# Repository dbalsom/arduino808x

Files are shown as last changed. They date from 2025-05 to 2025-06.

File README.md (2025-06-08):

# ArduinoX86
arduino8088_pcb

### About ArduinoX86
I've written a blog article that gives an overview of this project and how it is used.

https://martypc.blogspot.com/2023/06/hardware-validating-emulator.html

This project was originally called Arduino8088, but then I expanded it to support the 8086, and then the 80186, and have plans to support 80286, so it is now named the suitably generic ArduinoX86.

### Description

This project expands on the basic idea of controlling a CPU via a microcontroller's GPIO pins to clock the CPU and read and write control and data signals.
This can be used to validate an emulator's accuracy, but also as a general method of exploring the operation of a CPU's instructions and timings.
This project specifically targets early Intel and compatible CPUs, such as the 8088, 8086, NEC V20, V30, and specific variants of the the Intel 80186. Future support for the 80286 is planned.

Where it differs from existing Raspberry Pi-based projects is that it uses an Arduino DUE for the expanded number of GPIO pins available. The DUE has enough GPIO to operate 808X-compatible CPUs in Maximum mode. This enables several useful signals to be read such as the QS0 & QS1 processor instruction queue status lines, which give us more insight into the internal state of the CPU. We can also enable inputs such as READY, NMI, INTR, and TEST, so we can execute interrupts, NMIs, emulate wait states, and potentially even simulate FPU and DMA operations.

I have been using this project to validate the cycle-accuracy of my PC emulator, [MartyPC](https://github.com/dbalsom/martypc), and produce CPU test suites for emulators, covering the [8088](https://github.com/singleStepTests/8088/), [V20](https://github.com/SingleStepTests/v20) and [8086](https://github.com/singleStepTests/8086/) to date. 

This project has three main components:
  - The CPU server software, which runs on the Arduino, resets and initializes the CPU, loads the initial register state, then hands off control to the client, reading the final register state when complete.
  - The CPU client software, which runs on your computer and controls the CPU after the CPU server has set up initial register state as desired.
  - The CPU socket PCB HAT(s), which seat on top of the Arduino, and provide a physical interface between the CPU and GPIO lines.

The original Arduino8088 board utilized an Arduino MEGA, but this board is now considered deprecated for this project. As of the current release, an [Arduino DUE](https://store.arduino.cc/products/arduino-due) should be used instead. Although the DUE has 3v GPIO, the current board design is modified for 3V operation. Several models of the 80C88 tolerate 3V well despite being 5V parts, due to the low clock rate employed.

Support for the newer [Arduino GIGA](https://store.arduino.cc/products/giga-r1-wifi) is in development but not quite complete. Unfortunately it seems to have insufficient power supply on the 3V line compared to the DUE.

A PCB hat for the 80286 that supports level shifting between 5V and 3V is in the design phase.

### 8086 Support

Revision 1.1 of the Arduino8088 board supports the 8086 and NEC V30 by adding a connection for the 8086's BHE pin. 

### 80186 Support

The ArduinoX86 cpu_server sketch supports operation of a low-voltage 80186. See the BOM section below for compatible parts. 
There is no PCB for the 80186, you will need to use a breakout board and connect directly to the Arduino DUE's headers. See [Using an 80186](https://github.com/dbalsom/arduinoX86/wiki/Using-an-80186) for more information.

## Can the CPU be clocked fast enough with an Arduino?

In short, no. We are well past the published minimum cycle times when executing programs via a serial protocol, cycle by cycle. NMOS process chips will fail to function in strange ways when clocked below this threshold. The issue is "dynamic logic" - logic gates that lose their state if not refrehsed electrically within a frequent enough interval. To function with ArduinoX86 a CMOS process CPU with a fully static core should be employed. These chips can be clocked down to 0Hz and still function. A list of compatible CPUs is provided in the BOM below.

## Credits

Inspired by and borrows from the Pi8088 validator created by Andreas Jonsson as part of the VirtualXT project:

https://github.com/andreas-jonsson/virtualxt/tree/develop/tools/validator/pi8088

A very similar project is homebrew8088's Raspberry Pi Hat:

https://github.com/homebrew8088/pi86

## To use

If you are using an 8088, 8086, V20 or V30, and you don't want to order and build the PCB, connect the GPIO pins to the CPU on a breadboard as specified in the KiCad project schematic.

If you are using an 80186, see the [wiki](https://github.com/dbalsom/arduinoX86/wiki/Using-an-80186) for connection instructions.

The main ArduinoX86 sketch, cpu_server, operates a simple binary serial protocol to execute operations on the CPU and read and write data, status and control signals. This is designed for integration with an emulator or instruction test generator.

Additionally, there is a sketch, 'run_program', that will take any user-supplied register state and array of instruction bytes defined in the source code, execute it, and print cycle traces and final register state. This is useful for investigating the timing and operation of certain instructions without needing any external software integrations, however it is restricted in the number of memory reads or writes it can support, due to the limited RAM on the Arduino MEGA (8k!) 'run_program' does not currently support the DUE.

An example application for cpu_server is provided, written in Rust, in the /crates/exec_program directory. It demonstrates how to upload arbitrary code to the ArduinoX86 and display cycle traces. The client will emulate the entire address space and set up a basic IVT.

## PCB
pcb_shield50

KiCad project files for the PCB are supplied. 

Version 1.1 adds a connection for the 8086's BHE pin, which is used by the 8086/V30/80186/80286 to drive the upper half of the 16-bit data bus.

> [!WARNING]  
> Please read all the notes in the next section before ordering/assembling parts. Failure to heed warnings will cause damage to your Arduino.

> [!CAUTION]
> Depending on the CPU used and the presence of an 8288 support chip, you may exceed the rated 3V power supply of the Arduino DUE.
> If your Arduino immediately turns off or does not turn on at all, you are likely triggering the overcurrent protection.
> 
> You can cut off the 3V supply lead from the header socket and provide external power from the top of the HAT.
>
> DO NOT connect external power to the 3V header without cutting the pin to the Arduino! Feeding current back into 3V OUT can damage your Arduino.

# BOM
- A compatible CPU:
  - For 8088, I recommend a CMOS variant such as a Harris or Oki 80C88. CMOS versions of the 8088 and 8086 were made by a number of manufacturers; all of them should work.
  - For 8086, Intel directly produced an 80C86 which works, so you might as well use it. The Harris 80C86 has also been tested but has minor differences. 
  - The NEC V20 and V30 were CMOS process CPUs and work as well.
  - Some NMOS process CPUs may work - the AMD D8088 will work, but the AMD D8086-2 will not. The original Intel 8088 (C)1978 will not function properly.
  - For 80186, I recommend the Intel 80L186EB. See [Using an 80186](https://github.com/dbalsom/arduinoX86/wiki/Using-an-80186) for more information.

  - For 80286, a level-shifting HAT is required as no 3V 286 was produced. A CMOS variant such as the Harris 80C286 is required. The CPU should be a PLCC68 form factor.
    The 286 HAT is still in the design phase.

> [!TIP]
> Beware of counterfeits on eBay and other online vendors. A legitimate chip will not look shiny and new with perfect printing on it. At best, you may get a functional
> CPU that has been resurfaced and reprinted, but there's not telling what you're actualy testing. 

- Optional: If using an 8088 or 8086, you can socket an Intel 8288 or OKI 82C88 Bus Controller.
  A CMOS version it not necessarily required, but they use less power.
  
  The 8288 is easily emulated but its ALE output is used to drive the LED on the Arduino8088 HAT.
  Change the `EMULATE_8288` define to 0 if using a physical 8288.

- A set of Arduino stacking headers (also usable with DUE) 
https://www.amazon.com/Treedix-Stacking-Headers-Stackable-Compatible/dp/B08G4FGBPQ

- A DIP-40 and (optionally) DIP-20 socket
  - Optional but highly recommended: A ZIF socket such as [https://www.amazon.com/-/en/gp/product/B00B886OZI](https://www.amazon.com/-/en/gp/product/B00B886OZI)
    to avoid breaking pins on repeated insertions

- (2x) 0805 0.047uf bypass capacitors
  https://www.mouser.com/ProductDetail/80-C0805C473KARAUTO

- Optional: A 12mm, active buzzer with 7.6mm pin spacing. 

  - For DUE: A 3V piezoelectric, low power buzzer <= 6mA
    https://www.mouser.com/ProductDetail/Mallory-Sonalert/PK-11N40PQ?qs=SXHtpsd1MbZ%252B7jeUyAAOVA%3D%3D
    
  - For MEGA: Any 3-5V buzzer <= 30mA
 
> [!WARNING]  
> Only connect an electromagnetic buzzer if using an Arduino MEGA.  The DUE has much lower GPIO max current supply.

- (2x) 750Ohm resistors (for LEDs)
  https://www.mouser.com/ProductDetail/667-ERA-6AED751V

- (2x) Any 0805 ~2V LED of your choice with 1.8-1.9mA forward current
  - https://www.mouser.com/ProductDetail/604-APTD2012LCGCK (Green)
  - https://www.mouser.com/ProductDetail/604-APT2012LSECKJ4RV (Orange)
 
- RS232 board for debug output - choose gender based on your desired cabling
  - https://www.amazon.com/Ultra-Compact-RS232-Converter-1Mbps/dp/B074BMLM11 (male)
  - https://www.amazon.com/Ultra-Compact-RS232-Converter-Female/dp/B074BTGLJN (female)
    
> [!WARNING]  
> DO NOT connect 5V to the RS232 board on the Arduino DUE. You will feed 5V into the RX GPIO pin and cause irreperable damage.

# Project Structure

## /asm

Assembly language files, intended to be assembled with NASM. To execute code on the ArduinoX86, one must supply two
binary files, one containing the program to be executed, and one containing the register values to load onto the CPU
before program execution. 

## /crates/ard808x_client

A library crate that implements a client for the ArduinoX86's serial protocol.

## /crates/ard808x_cpu

A library crate built on top of the `ard808x_client` crate, this provides a `RemoteCpu` struct that models CPU state 
and can execute programs.

## /crates/exec_program

A binary implementing an interface for the `ard808x_cpu` crate that will load a provided register state binary and 
execute the specified program binary.

## /pcb

Contains the KiCad project files and Gerber files for the Arduino8088 PCB.

## /sketches/cpu_server

The main Arduino sketch for ArduinoX86. Implements a server for a serial protocol enabling remote control of a 16-bit
Intel CPU on the Arduino DUE.

## /sketches/run_program

An older sketch that can execute a program directly on the Arduino MEGA. Supports the 8088 only.

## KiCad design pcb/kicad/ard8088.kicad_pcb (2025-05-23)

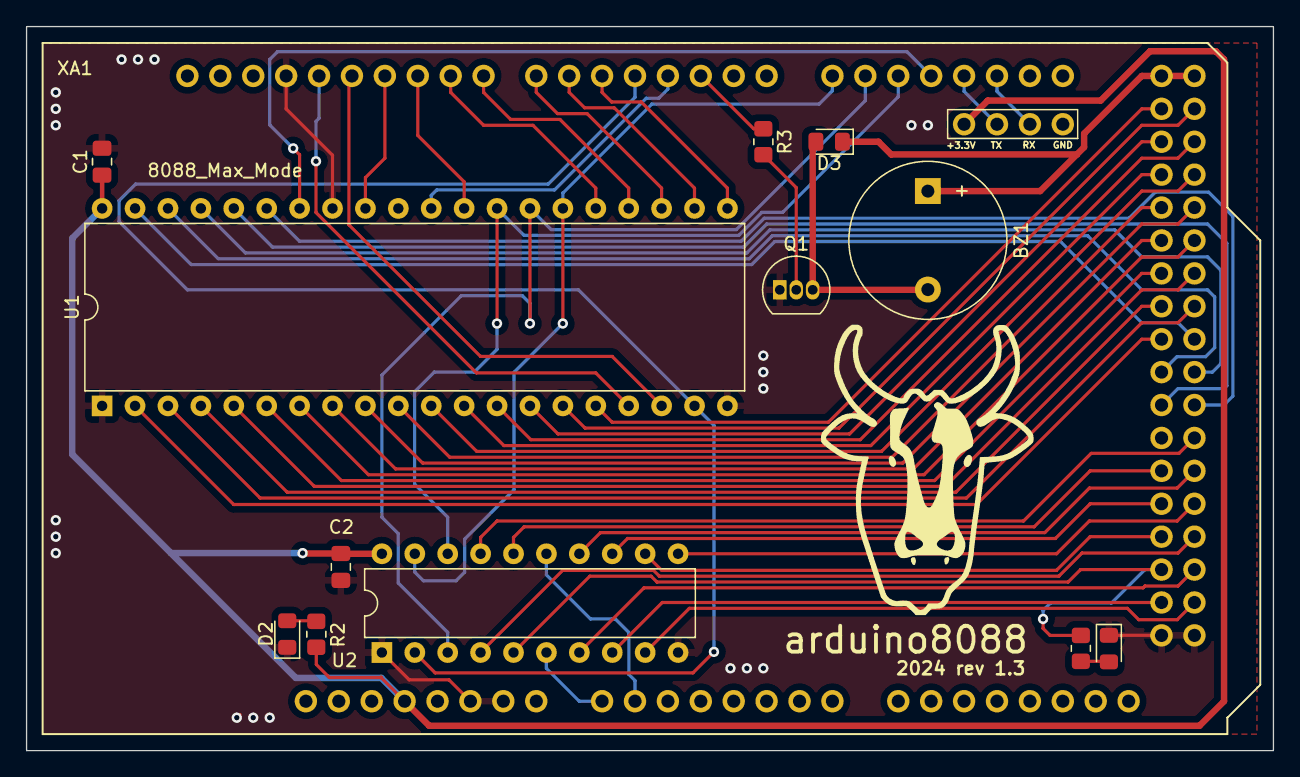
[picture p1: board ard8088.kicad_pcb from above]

Board: 2 copper layers, 96.2 x 55.9 mm, 13 parts (0 on the bottom side), 58 nets.

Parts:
BZ1: Buzzer; Buzzer_12x9.5RM7.6
C1, C2: 0.1uf; C_0805_2012Metric_Pad1.18x1.45mm_HandSolder
D1, D2: LED; LED_0805_2012Metric_Pad1.15x1.40mm_HandSolder
D3: 1N4148; D_0805_2012Metric_Pad1.15x1.40mm_HandSolder
Q1: PN2222A; TO-92_Inline
R1: R1; R_0805_2012Metric_Pad1.20x1.40mm_HandSolder
R2, R3: R; R_0805_2012Metric_Pad1.20x1.40mm_HandSolder
U1: 8088_Max_Mode; DIP-40_W15.24mm
U2: 8288; DIP-20_W7.62mm
XA1: Arduino_Mega2560_Shield

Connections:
+3.3V: C1.1, C2.1, R2.1, U1.40 (VCC), U2.20 (VCC), XA1.3V3 (3.3V), XA1.S0
+5V: BZ1.1 (-), D3.1 (K), XA1.5V3 (5V), XA1.5V4 (5V)
/A8: U1.8 (A8), XA1.D30
/A9: U1.7 (A9), XA1.D31
/A10: U1.6 (A10), XA1.D32
/A11: U1.5 (A11), XA1.D33
/A12: U1.4 (A12), XA1.D34
/A13: U1.3 (A13), XA1.D35
/A14: U1.2 (A14), XA1.D36
/A15: U1.39 (A15), XA1.D37
/A16: U1.38 (A16/S3), XA1.D38
/A17: U1.37 (A17/S4), XA1.D39
/A18: U1.36 (A18/S5), XA1.D40
/A19: U1.35 (A19/S6), XA1.D41
/AD0: U1.16 (AD0), XA1.D22
/AD1: U1.15 (AD1), XA1.D23
/AD2: U1.14 (AD2), XA1.D24
/AD3: U1.13 (AD3), XA1.D25
/AD4: U1.12 (AD4), XA1.D26
/AD5: U1.11 (AD5), XA1.D27
/AD6: U1.10 (AD6), XA1.D28
/AD7: U1.9 (AD7), XA1.D29
/ALE: R1.1, U2.5 (ALE), XA1.D50
/CEN: U2.15 (CEN), XA1.A1
/CLK: U1.19 (CLK), U2.2 (CLK), XA1.D4
/DEN: U2.16 (DEN), XA1.D44
/DT/~R: U2.4 (DT/~R), XA1.D49
/INTR: U1.18 (INTR), XA1.D12
/MCE/~PDEN: U2.17 (MCE/~PDEN), XA1.D43
/NMI: U1.17 (NMI), XA1.D13
/QS1: U1.24 (QS1), XA1.D8
/QSO: U1.25 (QS0), XA1.D9
/READY: U1.22 (READY), XA1.D6
/RESET: U1.21 (RESET), XA1.D5
/S0: U1.26 (~S0), U2.19 (~S0), XA1.D14 (D14_TX3)
/S1: U1.27 (~S1), U2.3 (~S1), XA1.D15 (D15_RX3)
/S2: U1.28 (~S2), U2.18 (~S2), XA1.D16 (D16_TX2)
/ser0: XA1.D18 (D18_TX1), XA1.S1
/ser1: XA1.D19 (D19_RX1), XA1.S2
/~AEN: U2.6 (~AEN), XA1.A0
/~AIOWC: U2.12 (~AIOWC), XA1.D48
/~AMWC: U2.8 (~AMWC), XA1.D52
/~BHE: U1.34 (HIGH), XA1.D17 (D17_RX2)
/~INTA: U2.14 (~INTA), XA1.D45
/~IORC: U2.13 (~IORC), XA1.D46
/~IOWC: U2.11 (~IOWC), XA1.D47
/~LOCK: U1.29 (~LOCK), XA1.D10
/~MRDC: U2.7 (~MRDC), XA1.D51
/~MWTC: U2.9 (~MWTC), XA1.D53 (D53_SS)
/~RD: U1.32 (~RD), XA1.D11
/~RQ/~GT1: U1.30 (~RQ/~GT1), XA1.D3 (D3_INT1)
/~TEST: U1.23 (~TEST), XA1.D7
GND: C1.2, C2.2, D1.1 (K), D2.1 (K), Q1.1 (E), U1.1 (GND), U1.20 (GND), U1.33 (MN/~MX), U2.1 (IOB), U2.10 (GND), XA1.GND1 (GND), XA1.GND2 (GND), XA1.GND3 (GND), XA1.GND5 (GND), XA1.GND6 (GND), XA1.S3
unnamed: BZ1.2 (+), D3.2 (A), Q1.3 (C)
unnamed: D1.2 (A), R1.2
unnamed: D2.2 (A), R2.2
unnamed: Q1.2 (B), R3.2
unnamed: R3.1, XA1.D2 (D2_INT0)

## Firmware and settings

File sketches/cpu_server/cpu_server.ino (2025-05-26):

/*
    Arduino8088 Copyright 2022-2025 Daniel Balsom
    https://github.com/dbalsom/arduino_8088

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
    THE SOFTWARE IS PROVIDED “AS IS”, WITHOUT WARRANTY OF ANY KIND, EXPRESS OR
    IMPLIED, INCLUDING BUT NOT LIMITED TO THE WARRANTIES OF MERCHANTABILITY,
    FITNESS FOR A PARTICULAR PURPOSE AND NONINFRINGEMENT. IN NO EVENT SHALL THE
    AUTHORS OR COPYRIGHT HOLDERS BE LIABLE FOR ANY CLAIM, DAMAGES OR OTHER   
    LIABILITY, WHETHER IN AN ACTION OF CONTRACT, TORT OR OTHERWISE, ARISING
    FROM, OUT OF OR IN CONNECTION WITH THE SOFTWARE OR THE USE OR OTHER
    DEALINGS IN THE SOFTWARE.
*/
#include <Arduino.h>
#include "arduino8088.h"
#include "cpu_server.h"
#include "opcodes.h"

static Server SERVER;
static Cpu CPU;
static Intel8288 I8288;

registers LOAD_REGISTERS = {
  0x0000, // AX
  0x0000, // BX
  0x0000, // CX
  0x0000, // DX
  0x0000, // SS
  0x0000, // SP
  0x0000, // FLAGS
  0x0000, // IP
  0xFFFF, // CS
  0x0000, // DS
  0x0000, // ES
  0x0000, // BP
  0x0000, // SI
  0x0000, // DI
};

// Register load routine. This program gets patched with the client supplied register values.
// It uses MOVs and POPs to set the register state as specified before the main program execution
// begins.
uint8_t LOAD_PROGRAM[] = {
  0x00, 0x00, 0xB8, 0x00, 0x00, 0x8E, 0xD0, 0x89, 0xC4, 0x9D, 0xBB, 0x00, 0x00, 0xB9, 0x00, 0x00,
  0xBA, 0x00, 0x00, 0xB8, 0x00, 0x00, 0x8E, 0xD0, 0xB8, 0x00, 0x00, 0x8E, 0xD8, 0xB8, 0x00, 0x00,
  0x8E, 0xC0, 0xB8, 0x00, 0x00, 0x89, 0xC4, 0xB8, 0x00, 0x00, 0x89, 0xC5, 0xB8, 0x00, 0x00, 0x89,
  0xC6, 0xB8, 0x00, 0x00, 0x89, 0xC7, 0xB8, 0x00, 0x00, 0xEA, 0x00, 0x00, 0x00, 0x00
};

// Patch offsets for load program
const size_t LOAD_BX = 0x0B;
const size_t LOAD_CX = 0x0E;
const size_t LOAD_DX = 0x11;
const size_t LOAD_SS = 0x14;
const size_t LOAD_DS = 0x19;
const size_t LOAD_ES = 0x1E;
const size_t LOAD_SP = 0x23;
const size_t LOAD_BP = 0x28;
const size_t LOAD_SI = 0x2D;
const size_t LOAD_DI = 0x32;
const size_t LOAD_AX = 0x37;
const size_t LOAD_IP = 0x3A;
const size_t LOAD_CS = 0x3C;

// CPU ID program. This is pretty simple - Intel CPUs have the undocumented and very fast instruction
// SALC at D6 - NEC CPUs have an undefined alias for XLAT that takes a lot longer. We can simply
// measure the execution time to determine Intel vs NEC.
// This routine is run first, in the reset vector, before the Jump program.

// Currently, this program must be able to be fetched in a single m-cycle, so it is limited to one
// opcode and an optional NOP for 16-bit CPUs.
const uint8_t CPUID_PROGRAM[] = {
  0xD6, 0x90
};

// 8080 Emulation enter program. This program executes the BRKEM opcode to enter 8080 emulation 
// on a compatible NEC CPU such as the V20 or V30.
// The first four bytes are used as the BRKEM vector segment and offset, and are patched with the 
// values of CS and IP.
uint8_t EMU_ENTER_PROGRAM[] = {
  0x00, 0x00, 0x00, 0x00, 0x0F, 0xFF, BRKEM_VECTOR
};

// 8080 Emulation exit program. This program executes PUSH PSW to preseve the 8080 flag state,
// then POP PSW to restore BP, then executes RETEM to exit emulation mode.
const uint8_t EMU_EXIT_PROGRAM[] = {
  0x00, 0x00, 0x00, 0x00, 0x00, 0x00, // 6 NOPs to hide program from client
  0xF5, 0x00, // PUSH PSW, NOP
  0x33, 0x33, // INX SP, INX SP to restore 8080 stack pointer
  0xED, 0xFD, // RETEM
};

// Far Jump program. We feed this program to the CPU at the reset vector. On an 8088 the reset 
// vector is at FFFF:0000 or address FFFF0 - giving us only 16 bytes to the end of the address
// space, where we will wrap around. We could wrap, but it gets a bit confusing, so instead 
// we'll jump to a clean new segment. The exact segment is configurable with LOAD_SEG which
// will get patched into this routine as the destination segment.
uint8_t JUMP_VECTOR[] = {
  0xEA, 0x00, 0x00, 0x00, 0x00
};

// Register store routine.
// Six NOPs have been padded to the front of the STORE routine to hide it from appearing in cycle
// traces.
// We can probably think of a better way to hide STORE program bytes, as this adds several cycles.
const uint8_t STORE_PROGRAM[] = {
  0x90, 0x90, 0x90, 0x90, 0x90, 0x90,
  0xE7, 0xFE, 0x89, 0xD8, 0xE7, 0xFE, 0x89, 0xC8, 0xE7, 0xFE, 0x89, 0xD0, 0xE7, 0xFE, 0x8C, 0xD0,
  0xE7, 0xFE, 0x89, 0xE0, 0xE7, 0xFE, 0xB8, 0x00, 0x00, 0x8E, 0xD0, 0xB8, 0x04, 0x00, 0x89, 0xC4,
  0x9C, 0xE8, 0x00, 0x00, 0x8C, 0xC8, 0xE7, 0xFE, 0x8C, 0xD8, 0xE7, 0xFE, 0x8C, 0xC0, 0xE7, 0xFE,
  0x89, 0xE8, 0xE7, 0xFE, 0x89, 0xF0, 0xE7, 0xFE, 0x89, 0xF8, 0xE7, 0xFE, 0xB0, 0xFF, 0xE6, 0xFD
};

uint8_t COMMAND_BUFFER[MAX_COMMAND_BYTES] = {0};

command_func V_TABLE[] = {
  &cmd_version,
  &cmd_reset,
  &cmd_load,
  &cmd_cycle,
  &cmd_read_address_latch,
  &cmd_read_status,
  &cmd_read_8288_command,
  &cmd_read_8288_control,
  &cmd_read_data_bus,
  &cmd_write_data_bus,
  &cmd_finalize,
  &cmd_begin_store,
  &cmd_store,
  &cmd_queue_len,
  &cmd_queue_bytes,
  &cmd_write_pin,
  &cmd_read_pin,
  &cmd_get_program_state,
  &cmd_get_last_error,
  &cmd_get_cycle_state,
  &cmd_cycle_get_cycle_state,
  &cmd_prefetch_store,
  &cmd_read_address,
  &cmd_cpu_type,
  &cmd_emu8080,
  &cmd_invalid
};

const size_t MAX_CMD = (sizeof V_TABLE / sizeof (command_func));

char LAST_ERR[MAX_ERR_LEN] = {0};

// Main Sketch setup routine
void setup() {
  SERIAL.begin(BAUD_RATE);
  Serial1.begin(DEBUG_BAUD_RATE);
  while (!SERIAL);
  while (!Serial1);
  
  // Wait for CPU to initialize
  delayMicroseconds(200);
  Serial1.write("Init\r\n", 6);  // More explicit raw write

  // Set all output pins to OUTPUT
  for( int p = 0; p < (sizeof OUTPUT_PINS / sizeof OUTPUT_PINS[0]); p++ ) {
    pinMode(OUTPUT_PINS[p], OUTPUT);
  }
  // Set all input pins to INPUT
  for( int p = 0; p < (sizeof INPUT_PINS / sizeof INPUT_PINS[0]); p++ ) {
    pinMode(INPUT_PINS[p], INPUT);
  }

  // Default output pin states
  digitalWrite(RQ_PIN, HIGH); // Don't allow other bus masters
  digitalWrite(READY_PIN, HIGH);
  digitalWrite(TEST_PIN, LOW);
  digitalWrite(INTR_PIN, LOW); // Must set these to a known value or risk spurious interrupts!
  digitalWrite(NMI_PIN, LOW);  // Must set these to a known value or risk spurious interrupts!
  digitalWrite(AEN_PIN, LOW); // AEN is enable-low
  digitalWrite(CEN_PIN, HIGH); // Command enable enables the outputs on the i8288

  // Patch the reset vector jump program
  patch_vector_pgm(JUMP_VECTOR, LOAD_SEG);

  cpu_id();

  CPU.v_state = Reset;

  beep(100);
  Serial1.println("Arduino8088 Server Initialized!");
  Serial1.flush();
  clear_error();
  
  SERVER.c_state = WaitingForCommand;
}

void reset_cpu_struct(bool reset_load_regs) {

  // Retain detected cpu type, width and emulation flags.
  cpu_type_t cpu_type = CPU.cpu_type;
  cpu_width_t width = CPU.width;
  bool do_emulation = CPU.do_emulation;
  registers_t load_regs = CPU.load_regs;

  // Zero the CPU struct
  memset(&CPU, 0, sizeof CPU);

  if(!reset_load_regs) {
    // Restore regs
    CPU.load_regs = load_regs;
  }

  // Restore retained values
  CPU.cpu_type = cpu_type;
  CPU.width = width;
  CPU.do_emulation = do_emulation;

  CPU.state_begin_time = 0;
  change_state(Reset);
  CPU.data_bus = 0x00; 
  init_queue();
}

bool cpu_id() {
    if (!cpu_reset()) {
        Serial1.println("cpu_id(): Failed to reset CPU!");
        set_error("Failed to reset CPU!");
        return false;
    }
    change_state(CpuId);
    uint32_t timeout = 0;
    while (CPU.v_state != LoadDone) {
        cycle();
        timeout++;
        if (timeout > 200) {
            Serial1.println("cpu_id(): CPU ID timeout!");
            set_error("CPU ID timeout!");
            return false;
        }
    }

    size_t t_idx = CPU.cpu_type;
    if (t_idx < CPU_TYPE_COUNT) {
      Serial1.print("cpu_id(): Detected CPU: ");
      Serial1.print(CPU_TYPE_STRINGS[CPU.cpu_type]);
      Serial1.println("");
    }
    else {
      Serial1.println("Bad CPU type!");
      return false;
    }

    return true;
}

// Read a byte from the data bus. The half of the bus to read is determined 
// by BHE and A0.
uint8_t data_bus_read_byte() {
  CPU.data_bus = data_bus_read(CPU.data_width);
  if (!READ_BHE_PIN) {
    // High byte is active.
    return (uint8_t)(CPU.data_bus >> 8);
  }
  else {
    // Low byte is active.
    return (uint8_t)CPU.data_bus;
  }
}

void data_bus_set_byte(uint8_t byte) {
    if (!READ_BHE_PIN) {
    // High byte is active.
    CPU.data_bus = ((uint16_t)byte) << 8;
  }
  else {
    // Low byte is active.
    CPU.data_bus = (uint16_t)byte;
  }
}

void clear_error() {
  strncpy(LAST_ERR, "No error", MAX_ERR_LEN - 1);
}

void set_error(const char *msg) {
  strncpy(LAST_ERR, msg, MAX_ERR_LEN - 1);
  Serial1.println("");
  Serial1.println("************ ERROR ************");
  Serial1.println(LAST_ERR);
  Serial1.println("*******************************");
  error_beep();
}

// Send a failure code byte in response to a failed command
void send_fail() {
  #if MODE_ASCII
    SERIAL.write(RESPONSE_CHRS[RESPONSE_FAIL]);
  #else
    SERIAL.write((uint8_t)RESPONSE_FAIL);
  #endif
}

// Send the success code byte in response to a successful command
void send_ok() {
  #if MODE_ASCII
    SERIAL.write(RESPONSE_CHRS[RESPONSE_OK]);
  #else
    SERIAL.write((uint8_t)RESPONSE_OK);
  #endif
}

void debug_proto(const char* msg) {
  #if DEBUG_PROTO
    Serial1.print("## ");
    Serial1.print(msg);
    Serial1.println(" ##");
  #endif
}

void debug_cmd(const char *cmd, const char* msg) {
  #if DEBUG_PROTO
    Serial1.print("## cmd ");
    Serial1.print(cmd);
    Serial1.print(": " );
    Serial1.print(msg);
    Serial1.println(" ##");
  #endif
}

// Server command - Version
// Send server identifier 'ard8088' followed by protocol version number in binary
bool cmd_version() {
  debug_cmd("VERSION", "In cmd");
  SERIAL.write((uint8_t *)VERSION_DAT, sizeof VERSION_DAT);
  SERIAL.write(VERSION_NUM);
  FLUSH;
  delay(10); // let USB complete the transaction
  Serial1.println("Got version query!");
  return true;
}

// Server command - Reset
// Attempt to reset the CPU and report status.
// This will be rarely used by itself as the register state is not set up. The Load 
// command will reset the CPU and set register state.
bool cmd_reset() {
  debug_cmd("RESET", "In cmd");
  bool result;
  snprintf(LAST_ERR, MAX_ERR_LEN, "NO ERROR");

  #if EMULATE_8288
    reset_i8288();
  #endif
  result = cpu_reset();
  if(result) {
    change_state(Execute);
  }
  return result;
}

// Server command - Cpu type
// Return the detected CPU type
bool cmd_cpu_type() {
  debug_cmd("CPU_TYPE", "In cmd");
  snprintf(LAST_ERR, MAX_ERR_LEN, "NO ERROR");
  SERIAL.write((uint8_t)CPU.cpu_type);
  return true;
}

// Server command - Cycle
// Execute a single CPU cycle
bool cmd_cycle() {
  cycle();
  return true;
}

// Server command - Load
// Load the specified register state into the CPU.
// This command takes 28 bytes, which correspond to the word values of each of the 14
// CPU registers.
// Registers should be loaded in the following order, little-endian:
//
// AX, BX, CX, DX, SS, SP, FLAGS, IP, CS, DS, ES, BP, SI, DI
bool cmd_load() {

  //Serial1.println(">> Got load!");
  snprintf(LAST_ERR, MAX_ERR_LEN, "NO ERROR");

  // Sanity check
  if(SERVER.cmd_byte_n < sizeof (registers_t)) {
    set_error("Not enough command bytes");
    return false;
  }

  // Write raw command bytes over register struct.
  // All possible bit representations are valid.
  uint8_t *read_p = (uint8_t *)&CPU.load_regs;

  for(size_t i = 0; i < sizeof (registers_t); i++ ) {
    *read_p++ = COMMAND_BUFFER[i];
  }

  patch_load_pgm(LOAD_PROGRAM, &CPU.load_regs);
  patch_brkem_pgm(EMU_ENTER_PROGRAM, &CPU.load_regs);

  Serial1.println("## Loaded CS ##");
  Serial1.println(CPU.load_regs.cs);
  LOAD_REGISTERS.flags &= CPU_FLAG_DEFAULT_CLEAR;
  LOAD_REGISTERS.flags |= CPU_FLAG_DEFAULT_SET;

  #if EMULATE_8288
    reset_i8288();
  #endif
  bool result = cpu_reset();
  if(!result) {
    //set_error("Failed to reset CPU");
    return false;
  }

  change_state(CpuId);

  // Run CPU and wait for load to finish
  int load_timeout = 0;
  while(CPU.v_state != Execute) {
    cycle();
    load_timeout++;

    if(load_timeout > 300) {
      // Something went wrong in load program
       set_error("Load timeout");
       return false;
    }
  }

  #if LOAD_INDICATOR
    Serial1.print(".");
  #endif
  debug_proto("LOAD DONE");
  return true;
}

// Server command - ReadAddressLatch
// Read back the contents of the address latch as a sequence of 3 bytes (little-endian)
bool cmd_read_address_latch() {
  static char buf[7];

  #if MODE_ASCII  
    //buf[0] = 0;
    snprintf(
      buf, 7, 
      "%02X%02X%02X",
      (int)(CPU.address_latch & 0xFF),
      (int)((CPU.address_latch >> 8) & 0xFF),
      (int)((CPU.address_latch >> 16) & 0xFF)
    );
    SERIAL.print(buf);
  #else
    SERIAL.write((uint8_t)(CPU.address_latch & 0xFF));
    SERIAL.write((uint8_t)((CPU.address_latch >> 8) & 0xFF));
    SERIAL.write((uint8_t)((CPU.address_latch >> 16) & 0xFF));
  #endif

  return true;
}

// Server command - ReadAddress
// Read back the contents of the address bus as a sequence of 3 bytes (little-endian)
bool cmd_read_address() {
  read_address();
  static char buf[7];

  #if MODE_ASCII  
    //buf[0] = 0;
    snprintf(
      buf, 7, 
      "%02X%02X%02X",
      (int)(CPU.address_bus & 0xFF),
      (int)((CPU.address_bus >> 8) & 0xFF),
      (int)((CPU.address_bus >> 16) & 0xFF)
    );
    SERIAL.print(buf);
  #else
    SERIAL.write((uint8_t)(CPU.address_bus & 0xFF));
    SERIAL.write((uint8_t)((CPU.address_bus >> 8) & 0xFF));
    SERIAL.write((uint8_t)((CPU.address_bus >> 16) & 0xFF));
  #endif

  return true;
}

bool cmd_invalid() {
  Serial1.println("Called cmd_invalid!");
  return false;
}

// Server command - ReadStatus
// Return the value of the CPU status lines S0-S5 and QS0-QS1
bool cmd_read_status() {
  static char buf[3];
  read_status0();
  #if MODE_ASCII  
    snprintf(buf, 3, "%02X", CPU.status0);
    SERIAL.print(buf);
  #else
    SERIAL.write(CPU.status0);
  #endif
  return true;
}

// Server command - Read8288Command
bool cmd_read_8288_command() {
  static char buf[3];
  read_8288_command_bits();
  #if MODE_ASCII  
    snprintf(buf, 3, "%02X", CPU.command_bits);
    SERIAL.print(buf);
  #else
    SERIAL.write(CPU.command_bits);
  #endif
  return true;
}

// Server command - Read8288Control
bool cmd_read_8288_control() {
  static char buf[3];
  read_8288_control_bits();
  #if MODE_ASCII  
    snprintf(buf, 3, "%02X", CPU.control_bits);
    SERIAL.print(buf);
  #else
    SERIAL.write(CPU.control_bits);
  #endif
  return true;
}

// Server command - ReadDataBus
bool cmd_read_data_bus() {
  static char buf[3];
  #if MODE_ASCII  
    snprintf(buf, 3, "%02X", CPU.data_bus);
    SERIAL.print(buf);
  #else
    SERIAL.write((uint8_t)CPU.data_bus);
    SERIAL.write((uint8_t)(CPU.data_bus >> 8));
  #endif

  return true;
}

// Server command - WriteDataBus
// Takes an argument of 2 bytes.
// Sets the data bus to the provided value. On 8-bit CPUs the upper byte is ignored.
// This should not be called for CODE fetches after we have called cmd_prefetch_store(), 
// unless a flow control operation occurs that flushes the queue and returns us to 
// within original program boundaries.
bool cmd_write_data_bus() {
  if (CPU.bus_state_latched == CODE) {
    // We've just been instructed to write a normal fetch byte to the bus.
    // If we were prefetching the store program, reset this status as a queue
    // flush must have executed (or we goofed up...)
    CPU.prefetching_store = false;
    CPU.s_pc = 0;
  }

  CPU.data_bus = (uint16_t)COMMAND_BUFFER[0];
  CPU.data_bus |= ((uint16_t)COMMAND_BUFFER[1] << 8);
  CPU.data_type = DATA_PROGRAM;
  return true;
}

// Server command - PrefetchStore
// Instructs the CPU server to load the next byte of the Store (or EmuExit) program early
// Should be called in place of cmd_write_data_bus() by host on T3/TwLast when 
// program bytes have been exhausted.
// (When we are prefetching past execution boundaries during main program execution)
bool cmd_prefetch_store() {

  if (CPU.in_emulation) {
    // Prefetch the EmuExit program
    if (CPU.s_pc >= sizeof EMU_EXIT_PROGRAM) {
      set_error("EmuExit program underflow");
      return false;
    }

    #if DEBUG_STORE
      Serial1.print("## PREFETCH_EMU_EXIT: s_pc: ");
    #endif

    CPU.prefetching_store = true;
    CPU.data_bus = read_program(EMU_EXIT_PROGRAM, &CPU.s_pc, CPU.address_latch, CPU.data_width);
    CPU.data_type = DATA_PROGRAM_END;
  }
  else {
    // Prefetch the Store program
    if (CPU.s_pc >= sizeof STORE_PROGRAM) {
      set_error("Store program underflow");
      return false;
    }

    #if DEBUG_STORE
      Serial1.print("## PREFETCH_STORE: s_pc: ");
    #endif

    CPU.prefetching_store = true;
    CPU.data_bus = read_program(STORE_PROGRAM, &CPU.s_pc, CPU.address_latch, CPU.data_width);
    CPU.data_type = DATA_PROGRAM_END;
  }

  #if DEBUG_STORE
    Serial1.print(CPU.s_pc);
    Serial1.print(" addr: ");
    Serial1.print(CPU.address_latch, 16);
    Serial1.print(" data: ");
    Serial1.println(CPU.data_bus, 16);
  #endif

  return true;
}

// Server command - Finalize
// Sets the data bus flag to DATA_PROGRAM_END, so that the Execute state can terminate
// on the next instruction queue fetch
bool cmd_finalize() {
  if(CPU.v_state == Execute) {
    change_state(ExecuteFinalize);

    // Wait for execute done state
    int execute_ct = 0;
    int timeout = FINALIZE_TIMEOUT;
    if (CPU.in_emulation) {
      // We need more time to exit emulation mode
      timeout = FINALIZE_EMU_TIMEOUT;
    }
    while(CPU.v_state != ExecuteDone) {
      cycle();
      execute_ct++;

      

      if(execute_ct > timeout) {
        set_error("cmd_finalize(): state timeout");
        return false;
      }
    }
    return true;
  }
  else {
    error_beep();
    set_error("cmd_finalize(): wrong state: ");
    Serial1.println(CPU.v_state);
    return false;
  }
}

// Server command - BeginStore
// Execute state must be in ExecuteDone before intiating BeginStore command
//
bool cmd_begin_store(void) {
  /*
  char err_msg[30];

  // Command only valid in ExecuteDone state
  if(CPU.v_state != ExecuteDone) {
    snprintf(err_msg, 30, "BeginStore: Wrong state: %d ", CPU.v_state);
    set_error(err_msg);
    return false;
  }

  change_state(Store);
  */
  return true;
}
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
void loop() {
  
  switch(SERVER.c_state) {

    case WaitingForCommand:
      if(SERIAL.available() > 0) {
        uint8_t cmd_byte = SERIAL.read();

        debug_cmd(CMD_STRINGS[cmd_byte], "received!");

        bool got_command = false;
        if(cmd_byte >= (uint8_t)CmdInvalid) {
          // Command is out of range, check against alias list
          for( uint8_t a = 0; a < sizeof CMD_ALIASES; a++) {
            if(cmd_byte == CMD_ALIASES[a]) {
              /*
              SERIAL.print("Got command alias: ");
              SERIAL.println(cmd_byte, HEX);
              */
              cmd_byte = a;
              got_command = true;
              break;
            }
          }

          if(!got_command) {
            send_fail();
            break;
          }
        }
        
        // Valid command, enter ReadingCommand state
        SERVER.cmd = (server_command)cmd_byte;

        if(cmd_byte == 0) {
          // We ignore command byte 0 (null command)
          break;
        }
        else if (cmd_byte > MAX_CMD) {
          // Cmd is out of range
          debug_proto("Command out of range!");
          break;
        }
        else if(CMD_INPUTS[cmd_byte] > 0) {
          // This command requires input bytes before it is executed.
          SERVER.cmd = (server_command)cmd_byte;
          SERVER.cmd_byte_n = 0;
          SERVER.c_state = ReadingCommand;
          SERVER.cmd_bytes_expected = CMD_INPUTS[cmd_byte];
          SERVER.cmd_start_time = millis(); // Get start time for timeout calculation
        }
        else {
          // Command requires no input, execute immediately
          bool result = V_TABLE[cmd_byte - 1]();
          if(result) {  
            debug_proto("Command OK!");
            send_ok();
          }
          else {
            debug_proto("Command FAIL!");
            send_fail();
          }
        }
      }
      break;

    case ReadingCommand:
      // The previously specified command requires paramater bytes, so read them in, or timeout
      if(SERIAL.available() > 0) {
        uint8_t cmd_byte = SERIAL.read();
        
        if(SERVER.cmd_byte_n < MAX_COMMAND_BYTES) {
          // Stil have bytes yet to read
          COMMAND_BUFFER[SERVER.cmd_byte_n] = cmd_byte;
          SERVER.cmd_byte_n++;
 
          if(SERVER.cmd_byte_n == SERVER.cmd_bytes_expected) {
            // We have received enough parameter bytes to execute the in-progress command.
            bool result = V_TABLE[SERVER.cmd - 1]();
            if(result) {  
              send_ok();
            }
            else {
              send_fail();
            }

            // Revert to listening for command
            SERVER.cmd_byte_n = 0;
            SERVER.cmd_bytes_expected = 0;
            SERVER.c_state = WaitingForCommand;
          }
        }
      }
      else {
        // No bytes received yet, so keep track of how long we've been waiting
        uint32_t now = millis();
        uint32_t elapsed = now - SERVER.cmd_start_time;

        if(elapsed >= CMD_TIMEOUT) {
          // Timed out waiting for parameter bytes. Send failure and revert to listening for command
          SERVER.cmd_byte_n = 0;
          SERVER.cmd_bytes_expected = 0;          
          SERVER.c_state = WaitingForCommand;
          debug_proto("Command timeout!");
          send_fail();
        }
      }
      break;
  }
}

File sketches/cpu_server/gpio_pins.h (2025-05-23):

/*
    Arduino8088 Copyright 2022-2025 Daniel Balsom
    https://github.com/dbalsom/arduino_8088

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
    THE SOFTWARE IS PROVIDED “AS IS”, WITHOUT WARRANTY OF ANY KIND, EXPRESS OR
    IMPLIED, INCLUDING BUT NOT LIMITED TO THE WARRANTIES OF MERCHANTABILITY,
    FITNESS FOR A PARTICULAR PURPOSE AND NONINFRINGEMENT. IN NO EVENT SHALL THE
    AUTHORS OR COPYRIGHT HOLDERS BE LIABLE FOR ANY CLAIM, DAMAGES OR OTHER   
    LIABILITY, WHETHER IN AN ACTION OF CONTRACT, TORT OR OTHERWISE, ARISING
    FROM, OUT OF OR IN CONNECTION WITH THE SOFTWARE OR THE USE OR OTHER
    DEALINGS IN THE SOFTWARE.
*/
#ifndef _ARDUINO8088_PINS_H
#define _ARDUINO8088_PINS_H

#define BIT00  (1u << 0)
#define BIT01  (1u << 1)
#define BIT02  (1u << 2)
#define BIT03  (1u << 3)
#define BIT04  (1u << 4)
#define BIT05  (1u << 5)
#define BIT06  (1u << 6)
#define BIT07  (1u << 7)
#define BIT08  (1u << 8)
#define BIT09  (1u << 9)
#define BIT10  (1u << 10)
#define BIT11  (1u << 11)
#define BIT12  (1u << 12)
#define BIT13  (1u << 13)
#define BIT14  (1u << 14)
#define BIT15  (1u << 15)
#define BIT16  (1u << 16)
#define BIT17  (1u << 17)
#define BIT18  (1u << 18)
#define BIT19  (1u << 19)
#define BIT20  (1u << 20)
#define BIT21  (1u << 21)
#define BIT22  (1u << 22)
#define BIT23  (1u << 23)
#define BIT24  (1u << 24)
#define BIT25  (1u << 25)
#define BIT26  (1u << 26)
#define BIT27  (1u << 27)
#define BIT28  (1u << 28)
#define BIT29  (1u << 29)
#define BIT30  (1u << 30)
#define BIT31  (1u << 31)

#define SET_BIT00  (1u << 0)
#define SET_BIT01  (1u << 1)
#define SET_BIT02  (1u << 2)
#define SET_BIT03  (1u << 3)
#define SET_BIT04  (1u << 4)
#define SET_BIT05  (1u << 5)
#define SET_BIT06  (1u << 6)
#define SET_BIT07  (1u << 7)
#define SET_BIT08  (1u << 8)
#define SET_BIT09  (1u << 9)
#define SET_BIT10  (1u << 10)
#define SET_BIT11  (1u << 11)
#define SET_BIT12  (1u << 12)
#define SET_BIT13  (1u << 13)
#define SET_BIT14  (1u << 14)
#define SET_BIT15  (1u << 15)

#define CLR_BIT00  ((1u << 0) << 16)
#define CLR_BIT01  ((1u << 1) << 16)
#define CLR_BIT02  ((1u << 2) << 16)
#define CLR_BIT03  ((1u << 3) << 16)
#define CLR_BIT04  ((1u << 4) << 16)
#define CLR_BIT05  ((1u << 5) << 16)
#define CLR_BIT06  ((1u << 6) << 16)
#define CLR_BIT07  ((1u << 7) << 16)
#define CLR_BIT08  ((1u << 8) << 16)
#define CLR_BIT09  ((1u << 9) << 16)
#define CLR_BIT10  ((1u << 10) << 16)
#define CLR_BIT11  ((1u << 11) << 16)
#define CLR_BIT12  ((1u << 12) << 16)
#define CLR_BIT13  ((1u << 13) << 16)
#define CLR_BIT14  ((1u << 14) << 16)
#define CLR_BIT15  ((1u << 15) << 16)

#if defined (ARDUINO_GIGA)
    // If Arduino GIGA

#elif defined(__SAM3X8E__) 
    // If Arduino DUE
    #define READ_PIN_D08      ((PIOC->PIO_PDSR & BIT22) != 0)
    #define READ_PIN_D09      ((PIOC->PIO_PDSR & BIT21) != 0)
    #define READ_PIN_D10      ((PIOC->PIO_PDSR & BIT29) != 0)

    #define READ_PIN_D14      ((PIOD->PIO_PDSR & BIT04) != 0)
    #define READ_PIN_D15      ((PIOD->PIO_PDSR & BIT05) != 0)
    #define READ_PIN_D16      ((PIOA->PIO_PDSR & BIT13) != 0)
    #define READ_PIN_D17      ((PIOA->PIO_PDSR & BIT12) != 0)
    #define READ_PIN_D18      ((PIOA->PIO_PDSR & BIT11) != 0)
    #define READ_PIN_D19      ((PIOA->PIO_PDSR & BIT10) != 0)

    #define READ_PIN_D38      ((PIOC->PIO_PDSR & BIT06) != 0)
    #define READ_PIN_D39      ((PIOC->PIO_PDSR & BIT07) != 0)
    #define READ_PIN_D40      ((PIOC->PIO_PDSR & BIT08) != 0)

    #define READ_PIN_D45      ((PIOC->PIO_PDSR & BIT18) != 0)
    #define READ_PIN_D46      ((PIOC->PIO_PDSR & BIT17) != 0)
    #define READ_PIN_D47      ((PIOC->PIO_PDSR & BIT16) != 0)
    #define READ_PIN_D48      ((PIOC->PIO_PDSR & BIT15) != 0)
    
    #define READ_PIN_D50      ((PIOC->PIO_PDSR & BIT13) != 0)
    #define READ_PIN_D51      ((PIOC->PIO_PDSR & BIT12) != 0)
    #define READ_PIN_D52      ((PIOB->PIO_PDSR & BIT21) != 0)
    #define READ_PIN_D53      ((PIOB->PIO_PDSR & BIT14) != 0)
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

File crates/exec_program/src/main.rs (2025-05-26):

use std::path::PathBuf;

use ard808x_client::*;
use ard808x_cpu::ard808x_client;
use ard808x_cpu::*;
use clap::Parser;

#[derive(Parser, Debug)]
#[command(author, version, about, long_about = None)]
struct Args {
    #[arg(long)]
    com_port: Option<String>,

    // The binary file containing the register data. Produced from an assembly
    // file 'program_regs.asm'
    #[arg(long, required(true))]
    reg_file: PathBuf,

    // The binary file containing the code to execute.
    #[arg(long, required(true))]
    bin_file: PathBuf,

    // Specify the address in memory to mount the bin file. This should typically
    // match the address specified by CS:IP, but doesn't have to...
    #[arg(long, required(true))]
    mount_addr: String,

    // Specify the number of wait states for every bus transfer.
    // TODO: Currently no division between memory and IO, should change...
    #[arg(long, default_value_t = 0)]
    wait_states: u32,

    // Enter 8080 emulation mode. Must have a compatible CPU such as a V20/V30.
    #[arg(long, default_value_t = false)]
    emu8080: bool,

    // Fill the prefetch queue before executing code.
    #[arg(long, default_value_t = false)]
    prefetch: bool,

    // Raise the INTR line on N cycles after HLT.
    #[arg(long, default_value_t = 0)]
    intr_after: u32,

    // Raise the INTR line on the specified cycle #.
    #[arg(long, default_value_t = 0)]
    intr_on: u32,

    // Raise the NMI line on the specified cycle #.
    #[arg(long, default_value_t = 0)]
    nmi_on: u32,
}

fn main() {
    env_logger::init();

    let args = Args::parse();

    // Parse commandline arguments
    let reg_bytes = std::fs::read(args.reg_file.clone()).unwrap_or_else(|e| {
        eprintln!("Couldn't read register file {:?}: {}", args.reg_file, e);
        std::process::exit(1);
    });

    let bin_bytes = std::fs::read(args.bin_file.clone()).unwrap_or_else(|e| {
        eprintln!("Couldn't read binary file {:?}: {}", args.bin_file, e);
        std::process::exit(1);
    });

    let mount_addr = u32::from_str_radix(&args.mount_addr, 16).unwrap_or_else(|e| {
        eprintln!(
            "Couldn't parse code mount address '{}': {}",
            args.mount_addr, e
        );
        std::process::exit(1);
    });

    if (mount_addr as usize) > (0xFFFFFusize - bin_bytes.len()) {
        eprintln!("Specified mount point out of range.");
        std::process::exit(1);
    }

    // Create a cpu_client connection to cpu_server.
    let cpu_client = match CpuClient::init(args.com_port.clone()) {
        Ok(ard_client) => {
            println!("Opened connection to Arduino_8088 server!");
            ard_client
        }
        Err(e) => {
            eprintln!("Error connecting to Arduino_8088 server: {e}");
            std::process::exit(1);
        }
    };

    // Create a remote cpu instance using the cpu_client which should now be connected.
    let mut cpu = RemoteCpu::new(
        cpu_client,
        args.prefetch,
        args.emu8080,
        args.wait_states,
        args.intr_on,
        args.intr_after,
        args.nmi_on,
    );

    let cpu_type = cpu.cpu_type();
    log::debug!("Detected CPU type: {:?}", cpu_type);

    // Capture initial regs before adjustment.
    let initial_regs = RemoteCpuRegisters::from(reg_bytes.as_slice());

    // Copy the binary to memory
    log::debug!("Mounting program code at: {:05X}", mount_addr);
    cpu.mount_bin(&bin_bytes, mount_addr as usize);

    // Set up IVR table
    cpu.setup_ivt();

    // Load the registers from binary file
    let result = cpu.load_registers_from_buf(&reg_bytes);
    if result {
        log::trace!("Successfully set up registers!");

        println!("Initial register state:");

        RemoteCpu::print_regs(&initial_regs, cpu_type);

        let print_opts = PrintOptions {
            print_pgm: true,
            print_preload: false,
            print_finalize: false,
        };

        //cpu.test();
        match cpu.run(Some(10_000), &print_opts) {
            Ok(regs) => {
                println!("Final register state:");
                RemoteCpu::print_regs_delta(&initial_regs, &regs, cpu_type);
            }
            Err(_) => {
                log::error!("Program execution failed!");
            }
        }
    } else {
        log::error!("Register setup failed: {}", cpu.get_last_error());
    }
}
